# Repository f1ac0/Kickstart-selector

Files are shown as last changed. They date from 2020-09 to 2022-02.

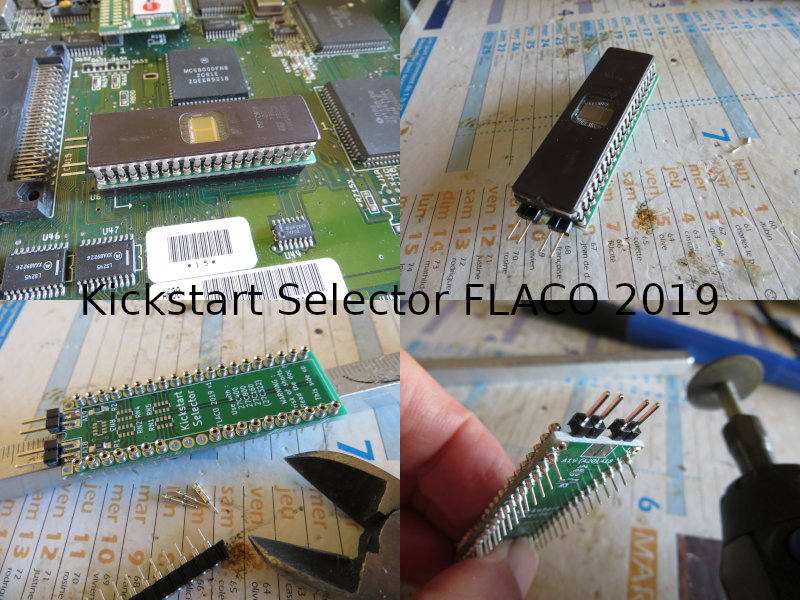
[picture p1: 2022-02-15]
Kickstart Selector FLACO 2019.JPG

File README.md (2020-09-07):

# Kickstart selector
Use a 1MB 27C800 or 2MB 27C160 ROM chip prepared with 2 or 4 kickstart images, select which one to boot your Amiga from.

You may also configure the board to use a 27C322 and 8 kickstart images, or 1MB kickstarts.

# Disclaimer
This is a hobbyist project, it comes with no warranty and no support. Also remember that the Amiga machines are about 30 years old and may fail because of such hardware expansions.

I publish this work using the CC-BY-NC-SA license.

If you find it useful and want to reward me : I am always looking for Amiga/Amstrad CPC hardware to repair and hack, please contact me.

# Making it
Check for shorts at least between 5V and GND traces before applying power !

- Use a socket /pin header with long enough pins that will connect to the computer socket through the PCB. I use pins taken from a round pin header strip
- Install R1 and R2. Leave RN unpopulated unless you know what you are doing.
- Chop pin 1 and 42 so that it does not make contact with the computer socket
- Install JP1 and JPN

## 1MB kickstarts
- Do NOT install R1
- Do NOT chop pin 1 
- Do NOT install JP1

## A500 Rev5 BUG
There is a bug on A500 Rev5 motherboards where the address line A17 is not routed to Pin 1 of its 40 socket but to Pin 31 instead (Byte/A20 of our EPROM). It affects operation of 512K kickstarts.
 1. Close JP4 : this connects Pins 1 and 31 of the computer socket
 2. Insulate the BYTE pin of the Eprom : Bend Pin 31 of the Eprom and connect it to Pin 22 (VCC, Pull-up to keep the EPROM in 16 bit mode).
 3. Do NEVER close JP3 ! That would cause a short between VCC and GND.
WARNING : never install the board in a computer not affected by the bug !

## SUPPORT FOR 27C322 AND 8 BANKS
 1. VERY IMPORTANT : chop the lead of the BYTE Pin 32 so that it does not make contact with the computer socket at any cost
 2. Install R3 and header JP3
If you need to install another type of ROM, then just leave JP3 open.

WARNING : to prevent making shorts between VCC and GND, never install header JP3 while the BYTE pin has not been removed.

# Using it
- Remove the ROM from the motherboard
- Burn and insert the UVPROM on the selector
- Insert the selector in the ROM socket of the motherboard. Make sure it does not pop out during operation.
- Close/open JP1, JP2 and JP3 accordingly
- Turn on the Amiga

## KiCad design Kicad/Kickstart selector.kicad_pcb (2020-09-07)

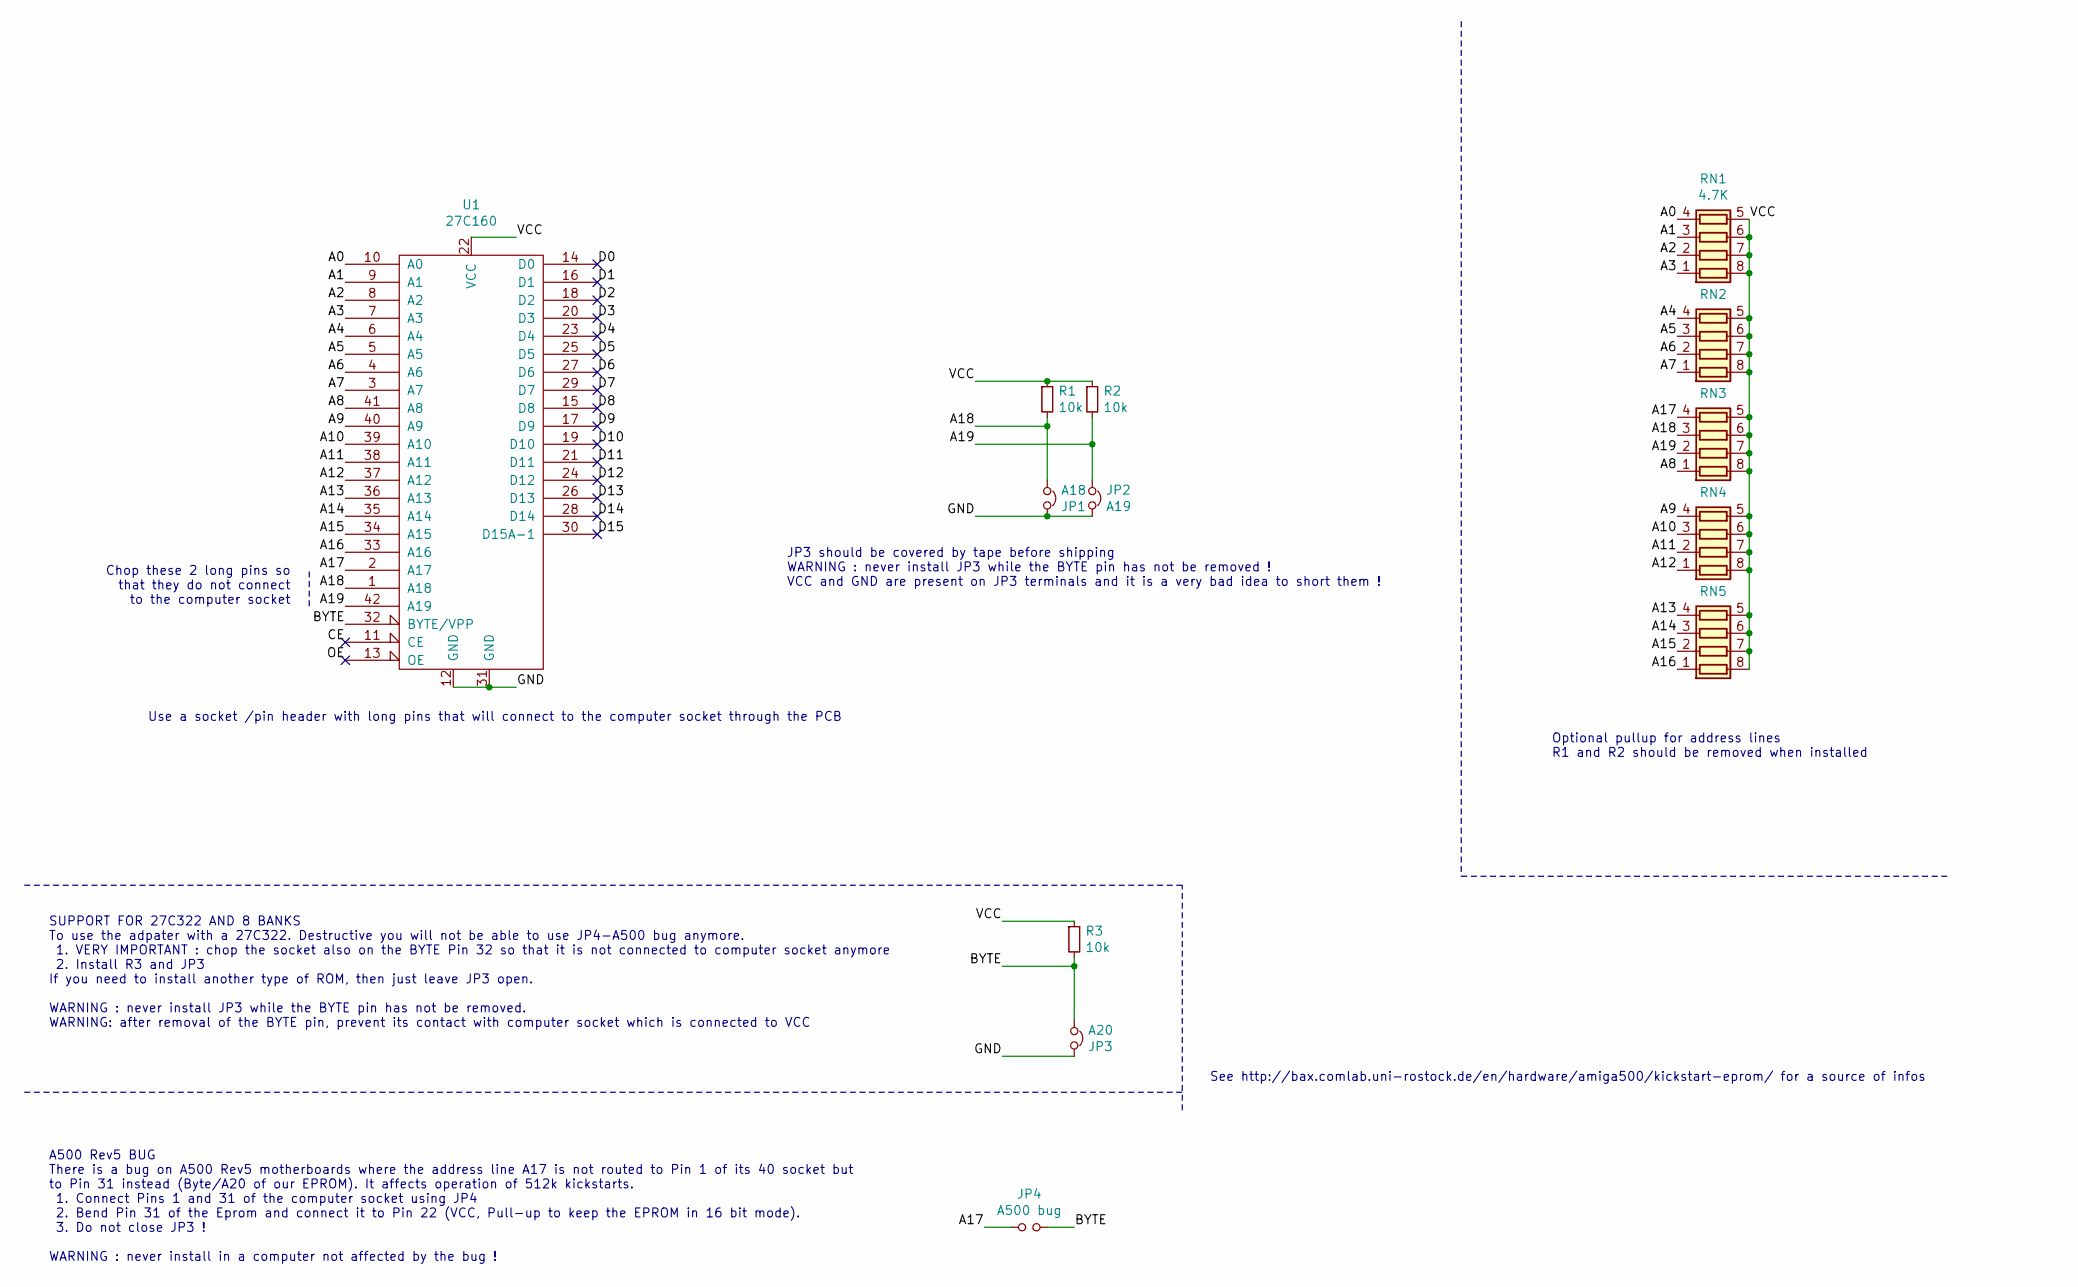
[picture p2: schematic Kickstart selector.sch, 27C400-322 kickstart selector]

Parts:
JP1: A18; Pin_Header_1x2_EdgeMount_Pitch2.54mm
JP2: A19; Pin_Header_1x2_EdgeMount_Pitch2.54mm
JP3: A20; Pin_Header_1x2_EdgeMount_Pitch2.54mm
JP4: A500 bug; SOLDER-JUMPER_1-WAY-CLOSED
R1, R2, R3: 10k; R_0805_HandSoldering
RN1, RN2, RN3, RN4, RN5: 4.7K; R_Array_Convex_4x0603
U1: 27C160; DIP-42_W15.24mm

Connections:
/A0: RN1.4 (R4.1), U1.10 (A0)
/A1: RN1.3 (R3.1), U1.9 (A1)
/A2: RN1.2 (R2.1), U1.8 (A2)
/A3: RN1.1 (R1.1), U1.7 (A3)
/A4: RN2.4 (R4.1), U1.6 (A4)
/A5: RN2.3 (R3.1), U1.5 (A5)
/A6: RN2.2 (R2.1), U1.4 (A6)
/A7: RN2.1 (R1.1), U1.3 (A7)
/A8: RN3.1 (R1.1), U1.41 (A8)
/A9: RN4.4 (R4.1), U1.40 (A9)
/A10: RN4.3 (R3.1), U1.39 (A10)
/A11: RN4.2 (R2.1), U1.38 (A11)
/A12: RN4.1 (R1.1), U1.37 (A12)
/A13: RN5.4 (R4.1), U1.36 (A13)
/A14: RN5.3 (R3.1), U1.35 (A14)
/A15: RN5.2 (R2.1), U1.34 (A15)
/A16: RN5.1 (R1.1), U1.33 (A16)
/A17: JP4.1, RN3.4 (R4.1), U1.2 (A17)
/A18: JP1.2, R1.2, RN3.3 (R3.1), U1.1 (A18)
/A19: JP2.1, R2.2, RN3.2 (R2.1), U1.42 (A19)
/BYTE: JP3.2, JP4.2, R3.2, U1.32 (BYTE/VPP)
/CE: U1.11 (CE)
/D0: U1.14 (D0)
/D1: U1.16 (D1)
/D2: U1.18 (D2)
/D3: U1.20 (D3)
/D4: U1.23 (D4)
/D5: U1.25 (D5)
/D6: U1.27 (D6)
/D7: U1.29 (D7)
/D8: U1.15 (D8)
/D9: U1.17 (D9)
/D10: U1.19 (D10)
/D11: U1.21 (D11)
/D12: U1.24 (D12)
/D13: U1.26 (D13)
/D14: U1.28 (D14)
/D15: U1.30 (D15A-1)
/GND: JP1.1, JP2.2, JP3.1, U1.12 (GND), U1.31 (GND)
/OE: U1.13 (OE)
/VCC: R1.1, R2.1, R3.1, RN1.5 (R4.2), RN1.6 (R3.2), RN1.7 (R2.2), RN1.8 (R1.2), RN2.5 (R4.2), RN2.6 (R3.2), RN2.7 (R2.2), RN2.8 (R1.2), RN3.5 (R4.2), RN3.6 (R3.2), RN3.7 (R2.2), RN3.8 (R1.2), RN4.5 (R4.2), RN4.6 (R3.2), RN4.7 (R2.2), RN4.8 (R1.2), RN5.5 (R4.2), RN5.6 (R3.2), RN5.7 (R2.2), RN5.8 (R1.2), U1.22 (VCC)

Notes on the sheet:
Chop these 2 long pins so that they do not connect to the computer socket
Use a socket /pin header with long pins that will connect to the computer socket through the PCB
Optional pullup for address lines R1 and R2 should be removed when installed
See http://bax.comlab.uni-rostock.de/en/hardware/amiga500/kickstart-eprom/ for a source of infos
JP3 should be covered by tape before shipping WARNING : never install JP3 while the BYTE pin has not be removed ! VCC and GND are present on JP3 terminals and it is a very bad idea to short them !
SUPPORT FOR 27C322 AND 8 BANKS To use the adpater with a 27C322. Destructive you will not be able to use JP4-A500 bug anymore. 1. VERY IMPORTANT : chop the socket also on the BYTE Pin 32 so that it is not connected to computer socket anymore 2. Install R3 and JP3 If you need to install another type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
A500 Rev5 BUG There is a bug on A500 Rev5 motherboards where the address line A17 is not routed to Pin 1 of its 40 socket but to Pin 31 instead (Byte/A20 of our EPROM). It affects operation of 512k kickstarts. 1. Connect Pins 1 and 31 of the computer socket using JP4 2. Bend Pin 31 of the Eprom and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

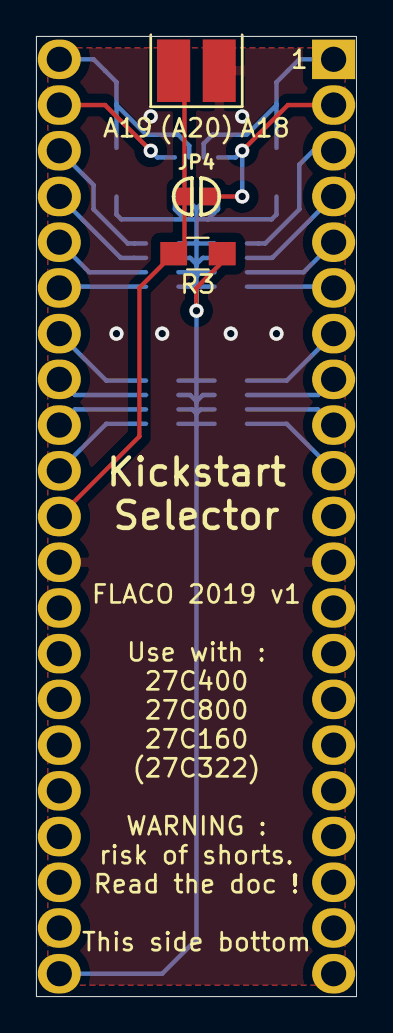
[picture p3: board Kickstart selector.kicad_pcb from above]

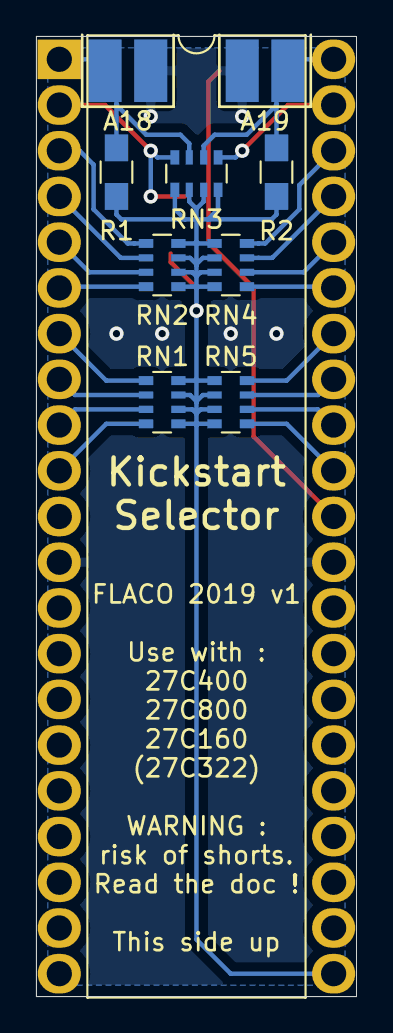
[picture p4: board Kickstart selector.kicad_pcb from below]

Board: 2 copper layers, 17.8 x 53.3 mm, 13 parts (10 on the bottom side), 23 nets.

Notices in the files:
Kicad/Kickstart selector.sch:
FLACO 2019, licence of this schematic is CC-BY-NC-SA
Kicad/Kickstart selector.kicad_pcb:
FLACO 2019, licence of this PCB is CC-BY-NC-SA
